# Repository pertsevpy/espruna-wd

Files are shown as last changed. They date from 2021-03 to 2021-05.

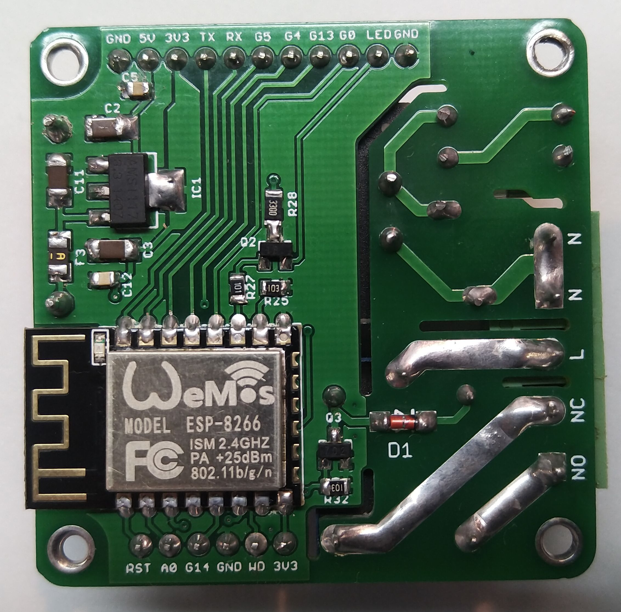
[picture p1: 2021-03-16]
img/assembled_bottom_01.jpg

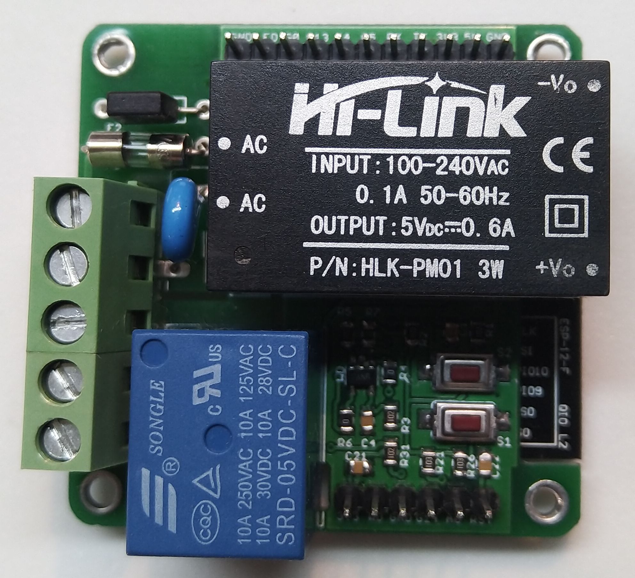
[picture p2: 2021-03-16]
img/assembled_top_01.jpg

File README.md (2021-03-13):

# espruna-wd
Remix [espurna-h PCB](https://github.com/xoseperez/espurna-board)

I didn't need current metering HLW8012, however needed an increase in reliability.

I used the [xoseperez](https://github.com/xoseperez) design to make the board using the Watch Dog hardware.

Changes:
- Added hardware Watch Dog timer circuit STMicroelectronics STWD100. It is possible to use pin-to-pin analogs. Pin Enable has 2 pull-up options. Enabled by a jumper.
- 3mm mounting holes (Little space, but dimensions are preserved).
- Slightly changed the layout of the board, redrawn all the tracks of the PCB.
- More GPIOs brought out.

# Watchdog Notes:
- Please use the jumper (pin enable) to disable WD while flashing and configuring the device. Otherwise, you will get flickering.
- Please use STWD100xY (eg WNY marking) with a timeout period of 1.6s (1.12 - 2.24s). Otherwise, the ESP8266 may not boot up in time and you will get flickering.

## Open Hardware

Hardware designs (schematics and CAD) files are licensed under the [Creative Commons Attribution-ShareAlike 3.0 Unported License](http://creativecommons.org/licenses/by-sa/3.0/) and follow the terms of the [OSHW (Open-source hardware) Statement of Principles 1.0.](http://freedomdefined.org/OSHW)

## Disclaimer

THIS PRODUCT IS TARGETED TO EXPERIENCED USERS AT THEIR OWN RISK. THIS PRODUCT IS MEANT TO BE USED PLUGGED TO MAINS AND IT REQUIRES A DEEP UNDERSTANDING OF THE PERILS OF HIGH VOLTAGE ON HUMAN LIFE.

TO THE FULLEST EXTENT PERMISSIBLE BY THE APPLICABLE LAW, I HEREBY DISCLAIM ANY AND ALL RESPONSIBILITY, RISK, LIABILITY AND DAMAGES ARISING OUT OF DEATH OR PERSONAL INJURY RESULTING FROM ASSEMBLY OR OPERATION OF THIS PRODUCT.

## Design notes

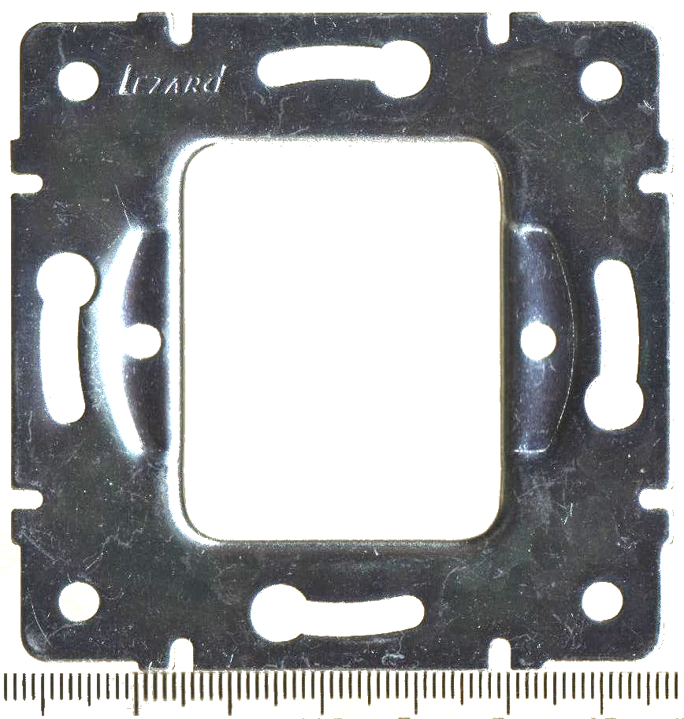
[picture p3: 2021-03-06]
stl/wall_socket.jpg

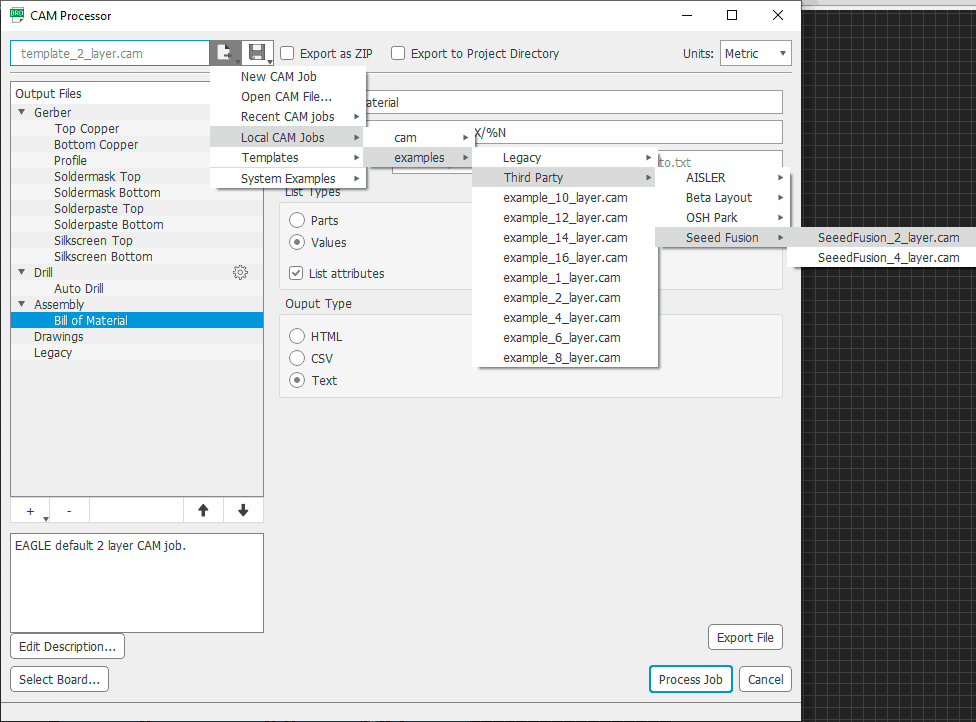
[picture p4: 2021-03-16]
cam_file/JLCPCB Eagle9 .png

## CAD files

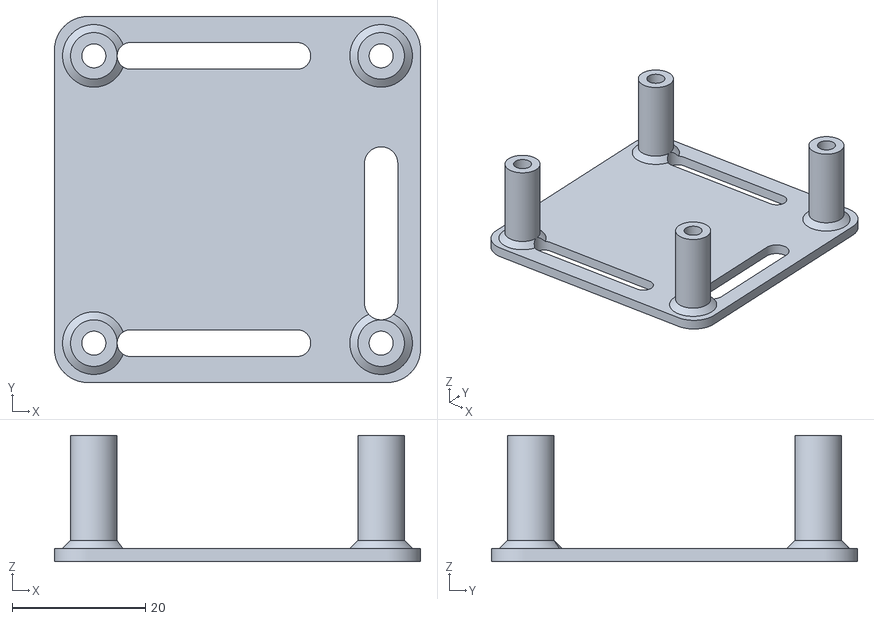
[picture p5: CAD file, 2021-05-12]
stl/wall_socket_cover.stl
55.0 x 55.0 x 19.0

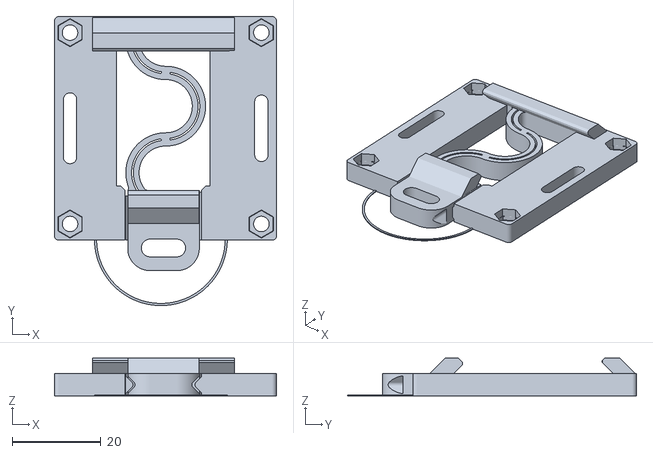
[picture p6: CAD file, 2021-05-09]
stl/DIN_mount_base.stl
50.1 x 65.2 x 8.50

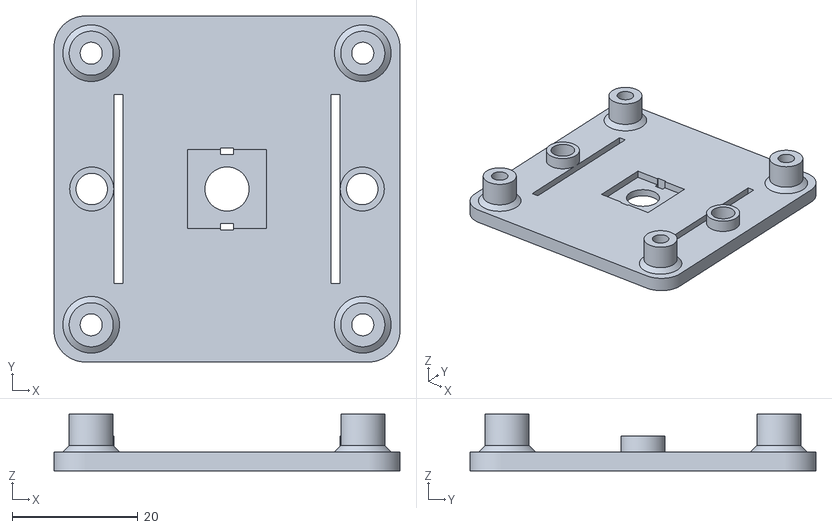
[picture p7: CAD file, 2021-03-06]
stl/wall_socket_base.stl
55.0 x 55.0 x 9.00

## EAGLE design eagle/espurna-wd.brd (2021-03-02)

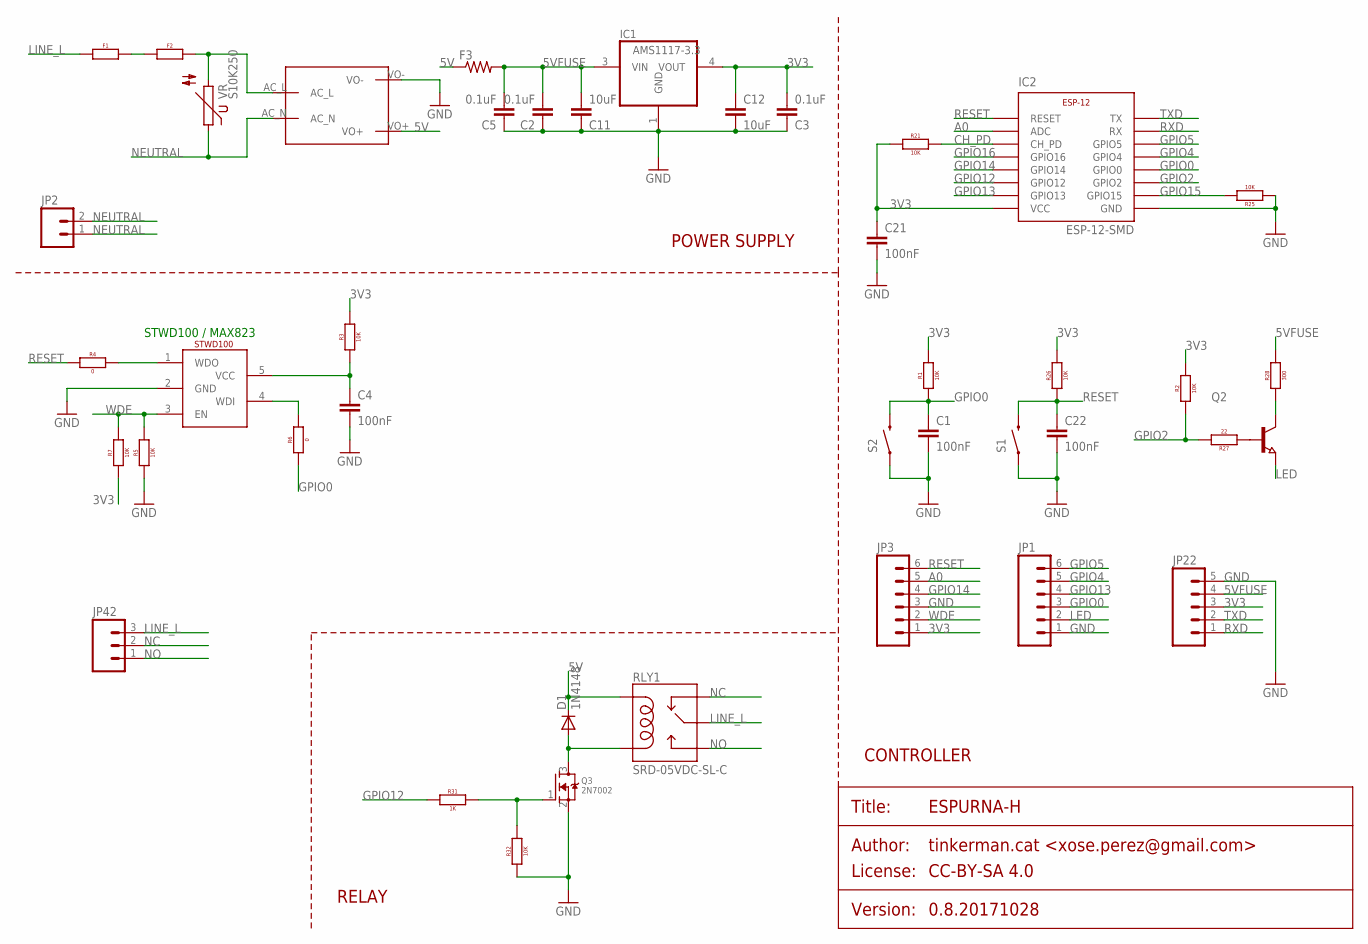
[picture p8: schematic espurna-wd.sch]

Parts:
C1, C4, C21, C22: 100nF; 0805
C2: 0.1uF; C1206K
C3, C5: 0.1uF; 0805
C11: 10uF; C1206K
C12: 10uF; C1206
D1: 1N4148; DO214BA
F1, F2: THERMALFUSE0.4; AXIAL-0.4
F3: RESISTOR1206; 1206
IC1: AMS1117-3.3; SOT223
IC2: ESP-12-SMD
JP1, JP3: M06NO_SILK_FEMALE_PTH; 1X06_NO_SILK
JP2: M02200MIL; SCREWTERMINAL-200MIL-2
JP22: M05PTH; 1X05
JP42: M03200MIL; SCREWTERMINAL-200MIL-3
Q2: NPN-TRANSISTOR_SOT23; SOT23
Q3: 2N7002; SOT23
R1, R2, R3, R5, R7, R21, R25, R26, R32: 10K; 0805
R4, R6: 0; 0805
R27: 22; 0805
R28: 300; 0805
R31: 1K; 0805
RLY1: SRD-05VDC-SL-C; SRD-5VDC-SL-C
S1, S2: SWITCH-MOMENTARY-2SMD-1101NE; TACTILE-SWITCH-1101NE
U$1: MAINS_CONVERTERS; HLK-PM01
VR: S10K250
WD: STWD100; SOT95P280X145-5N

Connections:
3V3: C3.2, C12.1, C21.1, IC1.4 (VOUT), IC2.VCC, JP3.1, JP22.3, R1.2, R2.2, R3.2, R7.1, R21.1, R26.2
5V: D1.C, F3.1, RLY1.COIL1, U$1.VO+
5VFUSE: C2.2, C5.2, C11.2, F3.2, IC1.3 (VIN), JP22.4, R28.2
A0: IC2.ADC, JP3.5
CH_PD: IC2.CH_PD, R21.2
GND: C1.2, C2.1, C3.1, C4.2, C5.1, C11.1, C12.2, C21.2, C22.2, IC1.1 (GND), IC2.GND, JP1.1, JP3.3, JP22.5, Q3.2 (S), R5.1, R25.1, R32.1, S1.1, S2.1, U$1.VO-, WD.2 (GND)
GPIO0: C1.1, IC2.GPIO0, JP1.3, R1.1, R6.1, S2.2
GPIO2: IC2.GPIO2, R2.1, R27.2
GPIO4: IC2.GPIO4, JP1.5
GPIO5: IC2.GPIO5, JP1.6
GPIO12: IC2.GPIO12, R31.1
GPIO13: IC2.GPIO13, JP1.4
GPIO14: IC2.GPIO14, JP3.4
GPIO15: IC2.GPIO15, R25.2
GPIO16: IC2.GPIO16
LED: JP1.2, Q2.2 (E)
LINE_L: F1.P$1 (1), JP42.3, RLY1.COMMON (MAIN)
LINE_P: F2.P$2 (2), U$1.AC_L, VR.2
unnamed: Q2.3 (C), R28.1
unnamed: Q2.1 (B), R27.1
unnamed: D1.A, Q3.3 (D), RLY1.COIL2
unnamed: Q3.1 (G), R31.2, R32.2
unnamed: C4.1, R3.1, WD.5 (VCC)
unnamed: F1.P$2 (2), F2.P$1 (1)
unnamed: R4.2, WD.1 (WDO)
unnamed: R6.2, WD.4 (WDI)
NC: JP42.2, RLY1.CLOSED (NC)
NEUTRAL: JP2.1, JP2.2, U$1.AC_N, VR.1
NO: JP42.1, RLY1.OPEN (NO)
RESET: C22.1, IC2.RESET, JP3.6, R4.1, R26.1, S1.2
RXD: IC2.RX, JP22.1
TXD: IC2.TX, JP22.2
WDE: JP3.2, R5.2, R7.2, WD.3 (EN)

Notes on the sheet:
POWER SUPPLY
RELAY
CONTROLLER
STWD100 / MAX823

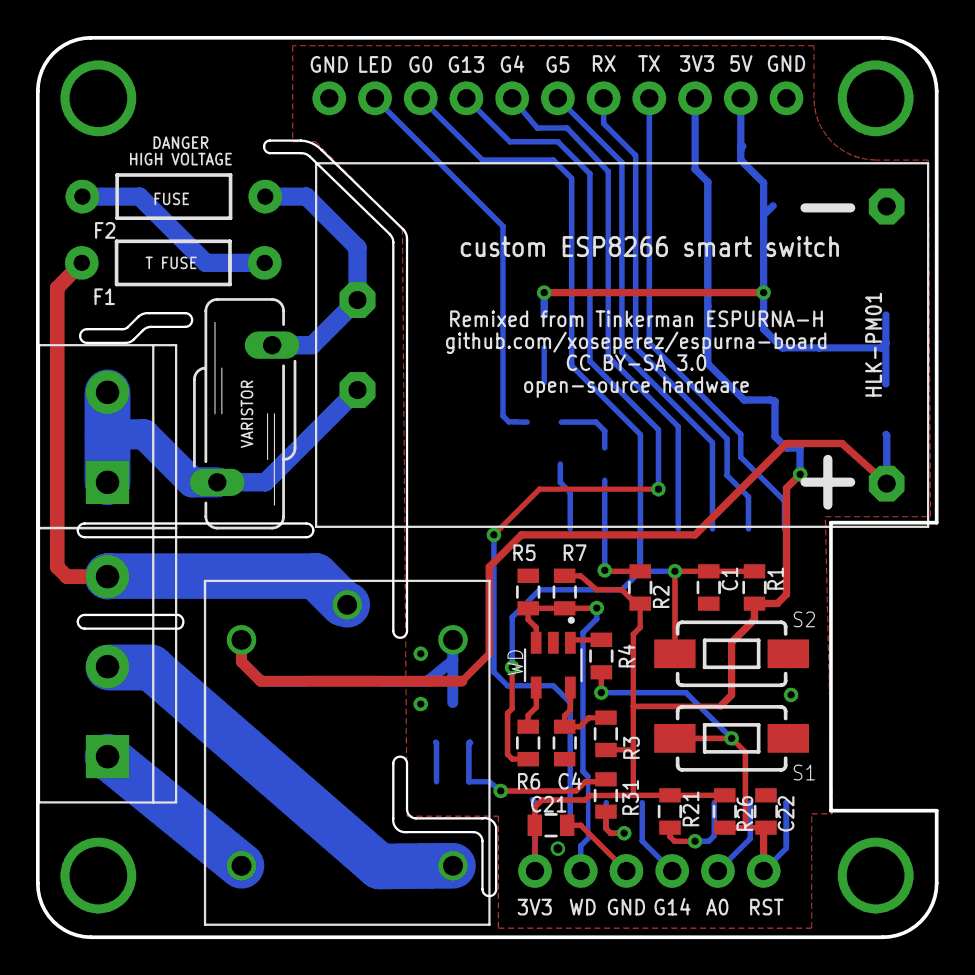
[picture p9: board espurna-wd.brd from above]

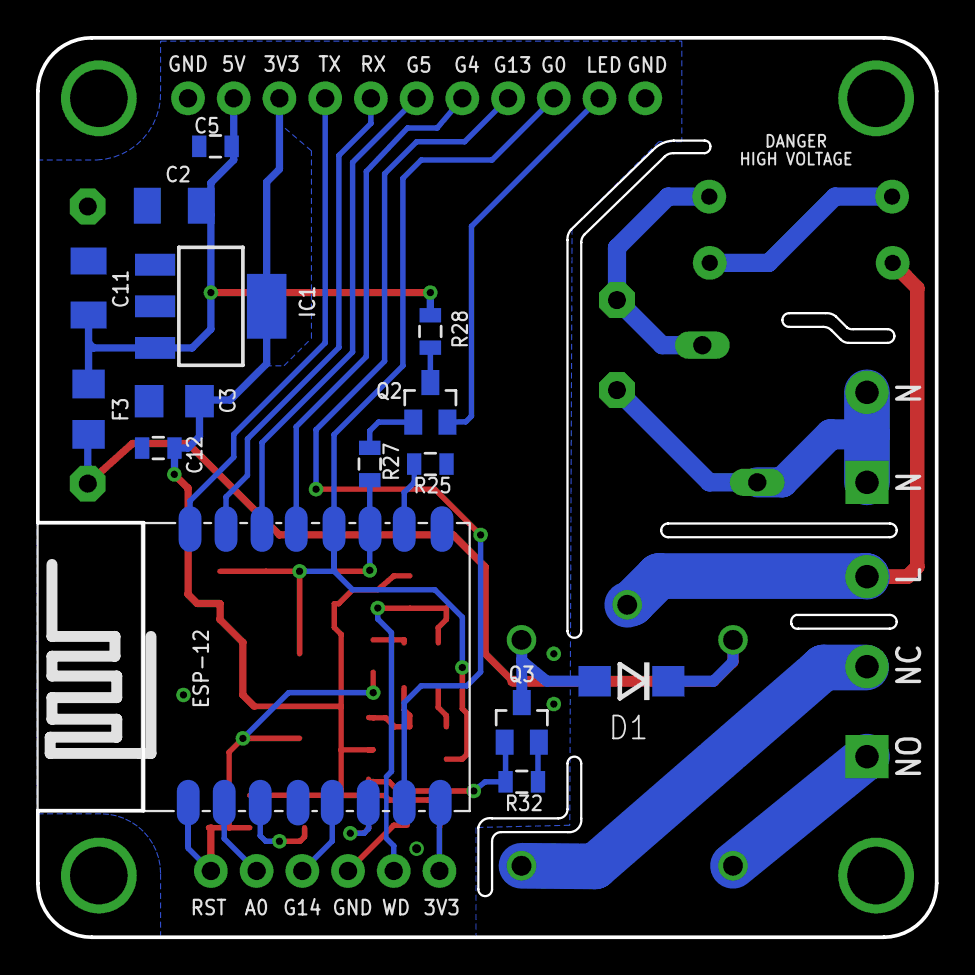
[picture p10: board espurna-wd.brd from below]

Board: 2 copper layers, 49.9 x 50.0 mm, 42 parts (15 on the bottom side), 32 nets.

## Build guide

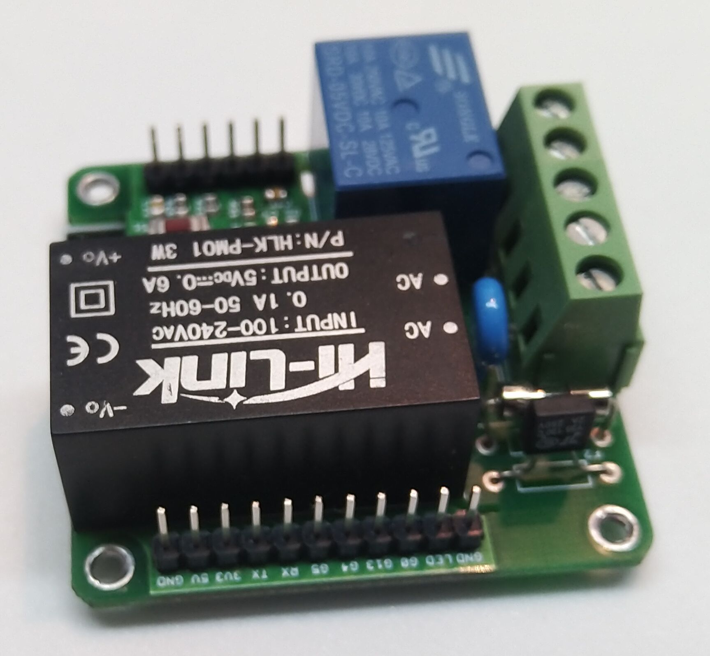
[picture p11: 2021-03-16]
img/assembled_top_03.jpg

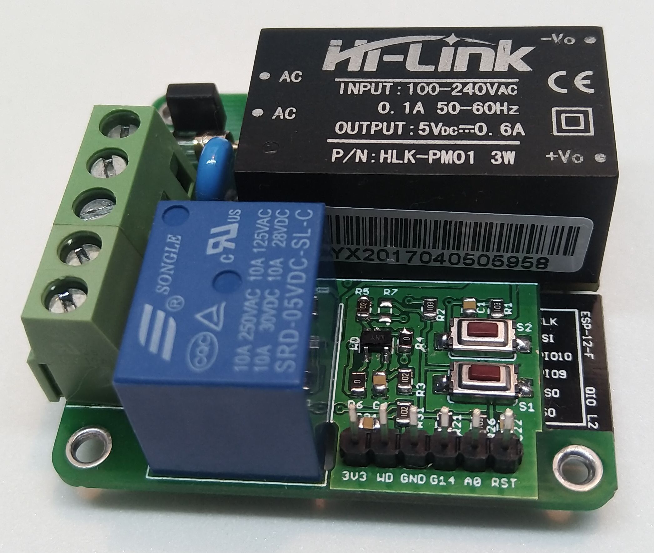
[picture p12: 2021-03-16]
img/assembled_top_02.jpg

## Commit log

2021-03-02 add PCB
    [espurna-wd.brd, espurna-wd.sch]
2021-03-04 Change dir
    [espurna-wd.brd, espurna-wd.sch]
2021-03-04 Add Gerber and CAM
    [espurna-wd.GBL, espurna-wd.GBO, espurna-wd.GBP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]
2021-03-06 Add stl models
    [base.stl, cover.stl]
2021-03-13 tmp file
    some renaming and ordering
    [espurna-wd.GBL, espurna-wd.GBO, espurna-wd.GBP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]
2021-03-13 TMP files
    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
    [espurna-wd.GBL, espurna-wd.GBO, espurna-wd.GBP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]
2021-05-09 Add DIN mount STL
    [DIN_mount_base.stl, wall_socket_base.stl, wall_socket_cover.stl]
2021-05-12 Update wall_socket_cover.stl
    small changes
    [wall_socket_cover.stl]

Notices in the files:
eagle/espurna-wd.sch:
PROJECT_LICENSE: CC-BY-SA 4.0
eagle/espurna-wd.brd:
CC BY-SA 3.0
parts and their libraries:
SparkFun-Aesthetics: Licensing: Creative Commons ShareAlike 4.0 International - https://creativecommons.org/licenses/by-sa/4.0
